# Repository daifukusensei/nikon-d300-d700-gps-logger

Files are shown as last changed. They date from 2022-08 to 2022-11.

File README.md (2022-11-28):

# Project Neptune: Arduino GPS w/ microSD logging and Bluetooth for Nikon D300(S)/D700
This is Project Neptune: an Arduino-based GPS data-logger for Nikon D300, D300S and D700 cameras with USB and Bluetooth connectivity.

<p align="center">
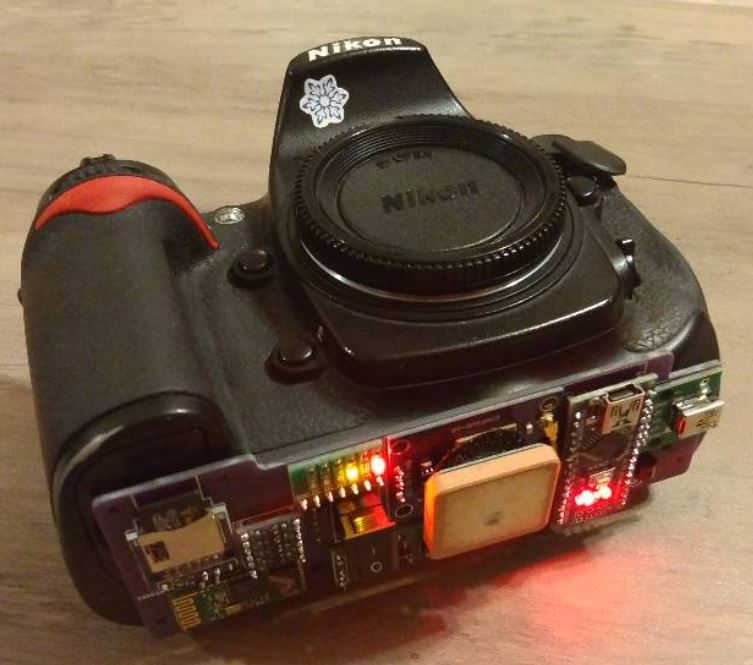
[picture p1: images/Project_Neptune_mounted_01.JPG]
  
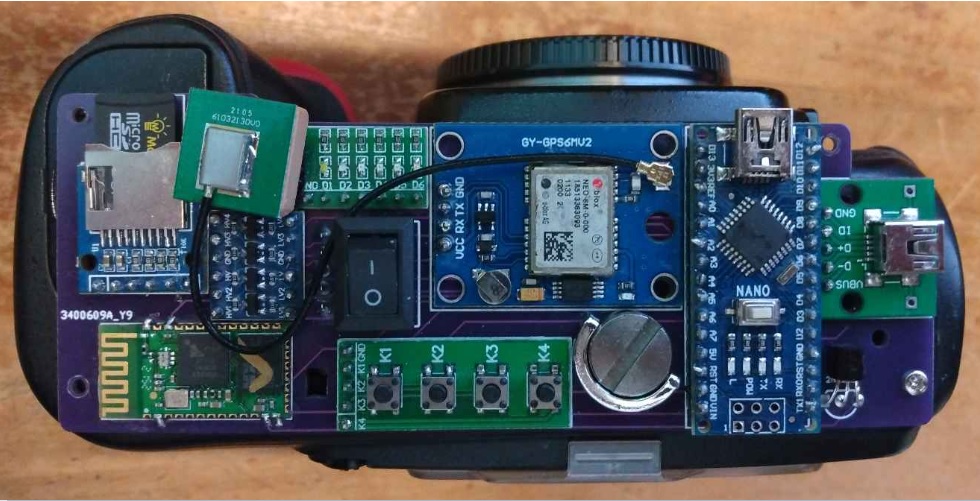
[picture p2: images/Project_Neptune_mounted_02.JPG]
  
</p>

## Why?
I'm an active travel photographer, and use various hardware & software-based GPS solutions to geo-tag my images, all with distinct shortcomings when paired with my ancient (but lovely) Nikon D700. So, I've built a geo-tagging device to meet my own specific needs. (See [Disclaimer](#Disclaimer).)

Leveraging what I've learned from an earlier attempt at a mobile GPS-solution (see [Project Pluto](https://github.com/daifukusensei/arduino-gps-logger)), I've affectionately named this Project Neptune.

## Features
- Mounts to the bottom of a Nikon D300(S)/D700
- Powered directly from camera independent of it being on or off
- Geo-tagging of captured images directly into EXIF metadata via USB-to-10-pin cable
- Logging of co-ordinates to microSD card at 2-second intervals
- Waypoint-marking of points of interest
- Bluetooth pairing with mobile phone or Serial Port Profile (SPP)NMEA 0183-compatible device/DSLR (PIN/passkey 0000)
- LEDs to indicate satellite and Bluetooth fix, and microSD card activity
- Individual features (microSD logging, Bluetooth and LEDs) may be toggled on or off, with settings retained across power-cycles

## Repository Contents
- [Arduino Sketch](./nikon-d300-s-d700-gps-logger.ino) for uploading to an Arduino Nano or compatible clone
- [Gerber file](./pcb/Project-Neptune-Gerber-PCB-v22.08.001.zip) for printing a PCB
- [EasyEDA project](./pcb/Project-Neptune-EasyEDA-project.zip) for modifying the PCB schematic
- [STL file](./stl/Project-Neptune-STL-cover.stl) for 3D-printing a cover

## Parts List
| Quantity | Description | Note |
| --- | --- | --- |
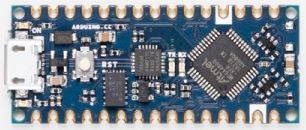
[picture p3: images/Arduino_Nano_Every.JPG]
Image of Arduino Nano Every
| 1 | Arduino Nano/Every or clone w/ soldered straight male headers |  |
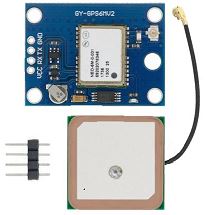
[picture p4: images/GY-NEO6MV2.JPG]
Image of GY-NEO6MV2
| 1 | u-blox NEO-6M GPS module w/ external antenna and built-in EEPROM, and soldered straight male header | Part GY-NEO6MV2:<br/> |
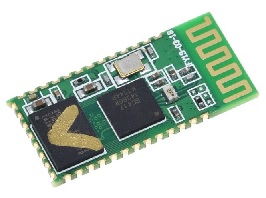
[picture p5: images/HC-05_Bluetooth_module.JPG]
Image of HC-05 Bluetooth module
| 1 | HC-05 Bluetooth module without carrier board |  |
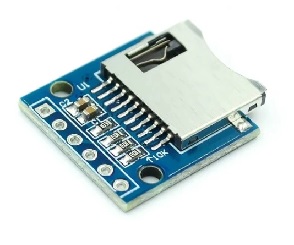
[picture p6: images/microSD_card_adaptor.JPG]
Image of SPI microSD card adaptor
| 1 | SPI microSD card adaptor w/ soldered straight male header | Of the following form-factor:<br/> |
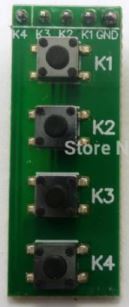
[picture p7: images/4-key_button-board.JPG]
Image of 4-key button-board module
| 1 | 4-key button-board module w/ soldered straight male header | |
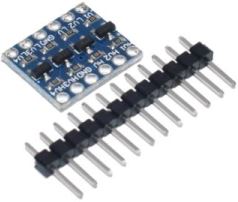
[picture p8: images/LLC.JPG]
Image of LLC
| 1 | 4-channel 3.3V/5V bi-directional logic-level-converter (LLC) w/ soldered straight male headers | Of the following form-factor:<br/> |
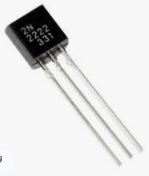
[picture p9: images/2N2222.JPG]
Image of 2N2222
| 1 | 2N2222 NPN transistor | For turning on and off the HC-05 Bluetooth module<br/> |
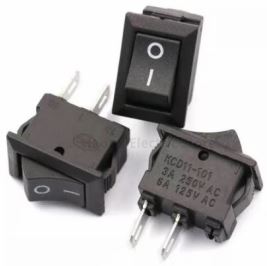
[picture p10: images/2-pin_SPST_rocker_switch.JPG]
Image of 2-pin SPST rocker switch
| 1 | 2-pin SPST rocker switch | 15mm\*10mm, in the following form-factor:<br/> |
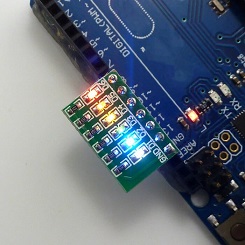
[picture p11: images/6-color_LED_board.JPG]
Image of LED board
| 1 | 3.3V/5V/12V 6-color LED board | Of the following form-factor:<br/> |
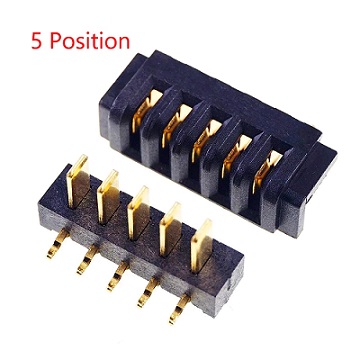
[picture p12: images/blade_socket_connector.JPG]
Image of Blade socket connector
| 1 | 5-position 2.5mm pitch female blade socket connector |  |
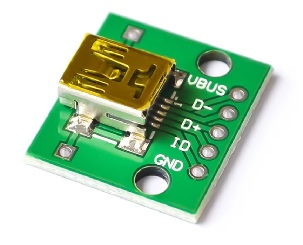
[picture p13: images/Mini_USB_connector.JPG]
Image of Mini-USB connector
| 1 | Female Mini-USB connector on 2.54mm pitch breakout board | Approximately 20mm*18mm, in the following form-factor:<br/>  |
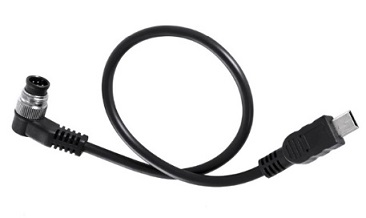
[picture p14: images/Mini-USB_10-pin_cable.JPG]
Image of Mini-USB to 10-pin cable
| 1 | Mini-USB to 10-pin cable | For connecting Project Neptune to the Nikon D300(S)/D700. The cable used for the *Micnova GPS-N1* GPS works fine; otherwise, if making your own, USB pin 3 connects to camera's RX, and USB pin 5 to GND<br/>  |
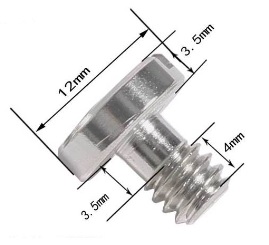
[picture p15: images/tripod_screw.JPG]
Image of tripod screw
| 1 | 1/4-inch tripod screw w/ head diameter no larger than 12mm | For securing Project Neptune to the camera-- the smaller and shorter the better so as to not make contact with PCB components:<br/>  |

## Libraries and Compile Requirements
Project Neptune uses the following libraries:
- [EEPROM](https://www.arduino.cc/en/Reference/EEPROM)
- [NeoGPS](https://github.com/SlashDevin/NeoGPS)
- [SdFat](https://github.com/greiman/SdFat)
- [SoftwareSerial](https://www.arduino.cc/en/Reference/softwareSerial)
- [SPI](https://www.arduino.cc/en/reference/SPI)

I had to do the following to compile against the Arduino Nano *Every*, though these changes may no longer be required and are not needed if an older Arduino Nano is used:
- NeoGPS: remove the `class Print` forward declarations from the following files:
    - DMS.h
    - NeoTime.h
- SdFat: set `SPI_DRIVER_SELECT` to `1` in **SdFatConfig.h** per [greiman/SdFat-beta#42](https://github.com/greiman/SdFat-beta/issues/42)
- Change `#define F(str) (str)` in **Arduino.h** to `#define F(str) (const __FlashStringHelper*)(str)`

## Build Instructions
1. Upload [nikon-d300-s-d700-gps-logger.ino](./nikon-d300-s-d700-gps-logger.ino) to an *Arduino Nano* or *Arduino Nano Every*
2. [Print a PCB](https://jlcpcb.com/) from this repository's Gerber file, with the following settings:
    - 2 layers
    - 1.6mm PCB thickness
3. Due to close proximity of other components on the top-side of the PCB, first solder the *5-position 2.5mm pitch female blade socket connector* to the bottom-side of the board, ensuring connector's pins are facing toward the *centre* of the PCB
4. Solder remaining components to their respective place on the PCB according to their footprint (see [image of PCB's top-side](./pcb/images/Project_Neptune_PCB_populated_top.JPG))
5. Find a place to secure your GPS antenna of choice; I've elected to sandwich mine between the *3.3V/5V/12V 6-color LED board* and *SPI microSD card adaptor* using velcro (see [image of PCB's top-side](./pcb/images/Project_Neptune_PCB_populated_top.JPG))
6. Attach Project Neptune to your Nikon D300(S)/D700 using a *1/4-inch tripod screw*. In order to ensure a secure connection, I've had to experiment with tripod screws of various sizes along with using a rubber washer (see [image of completed Project Neptune](./images/Project_Neptune_mounted_02.JPG)). Many holes are situated along the perimeter of the PCB to allow the use of M2 screws and standoffs should additional support be needed
7. Plug the *Mini-USB to 10-pin cable* into the PCB's USB port (**not** the Arduino's USB port!) and the camera
8. Insert a FAT32-formatted microSD card and power on Project Neptune

## Operations

### Startup Sequence
1. Any user-changed settings are restored from EEPROM
2. If **Waypoint-Marker** button is held, the HC-05 Bluetooth module is re-configured as follows:
	1. Baud rate set to 4800 as required for Nikon D300(S)/D700 connectivity
	2. PIN set to 0000
	3. Device name set to *Nikon-D300(S)-D700-GPS-Logger*
3. Initialize access to microSD card if one's inserted; else disable logging
4. Set baud rate of u-blox NEO-6M GPS module to 4800 as required for Nikon D300(S)/D700 connectivity
5. Set compatibility mode on u-blox NEO-6M GPS module and co-ordinate-system to 4-decimal places as required for Nikon D300(S)/D700 connectivity
6. Up-and-running

### Button Functions
| Button | Long-Press (3-seconds) |
| --- | --- |
| **Logging Button** (**K1** on button-board; **D5** on PCB) | Toggle logging to microSD card on and off |
| **Bluetooth Button** (**K2** on button-board; **D6** on PCB) | Toggle Bluetooth on and off |
| **Waypoint-Marker Button** (**K3** on button-board; **D7** on PCB) | **During normal use:**<br/>- Record current co-ordinates in file on microSD card, regardless of logging state<br/>- Requires a satellite-fix and microSD card *inserted at boot*<br/><br/>**During startup:**<br/>- Re-configure HC-05 Bluetooth module as follows: baud rate set to 4800 as required for Nikon D300(S)/D700 connectivity; PIN set to 0000; device name set to *Nikon-D300(S)-D700-GPS-Logger* |
| **LED Button** (**K4** on button-board; **D8** on PCB) | Toggle LEDs on and off |

### LED Behaviour
- **GPS** (red LED on LED board)
    - Blink: No satellite-fix
    - Solid: Satellite-fix
- **Logging** (yellow LED on LED board)
    - Blink: microSD card activity
    - Solid: microSD card not inserted at boot or error writing to card
- **Bluetooth** (blue LED on LED board)
    - Blink: Searching
    - Solid: Paired
    - Off: Bluetooth is disabled
- Long-pressing a button to toggle individual settings on and off results in the respective LED being lit for 2-seconds to visually indicate a state change

### microSD Card Behaviour
- When logging is on:
  1. File **yymmdd_log_nn.txt** is created in the root of the microSD card with a header row each time logging state is changed to **ON** and a date & time is acquired from the GPS (where **yymmdd** equals current UTC date, and **nn** equals incrementing number beginning with 00)
  2. Given a satellite-fix, the following comma-delimited fields are appended to the file at 2-second intervals
     - Latitude
     - Longitude
     - Speed (km/h)
     - Heading (degrees)
     - Altitude (floating-point meters)
     - Date and Time (UTC)
- Waypoint-markers are appended to file **waypoints.txt** in the same format as above, regardless of logging state

## Disclaimer
**Build and use at your own risk.** I am not an electrical engineer, nor a working C++ developer; this is a passion-project constructed in between numerous daddy duties, household chores, and long working hours. That said, it functions as intended, and has yet to blow up.

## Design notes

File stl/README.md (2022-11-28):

# Project Neptune: STL File
For 3D-printing a cover to protect the board

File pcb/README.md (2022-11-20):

# Project Neptune: EasyEDA Project and Gerber File

<p align="center">
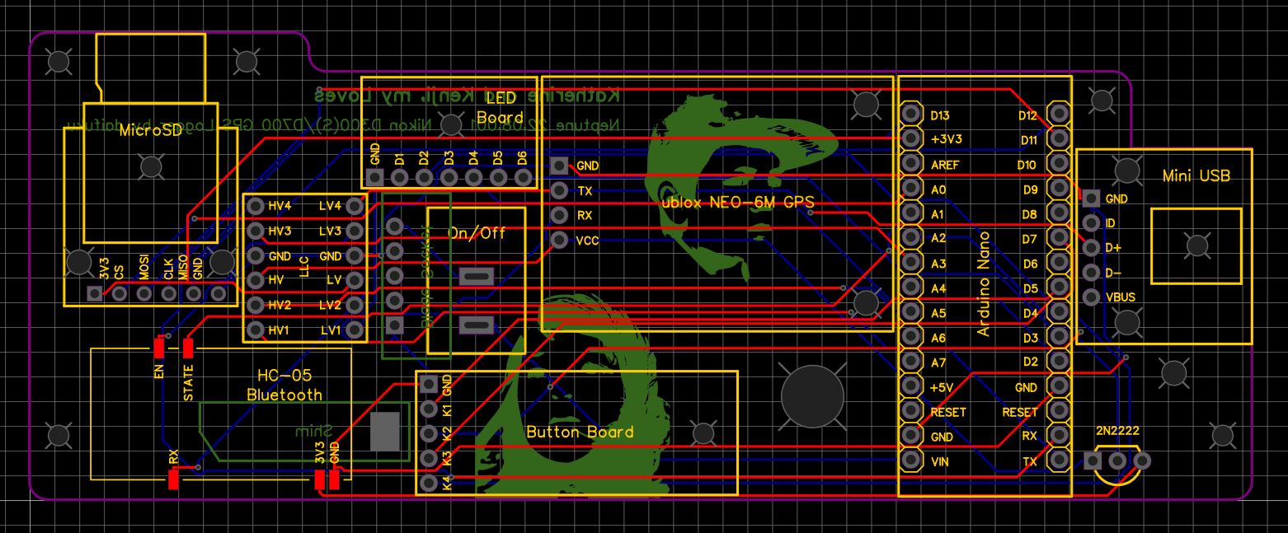
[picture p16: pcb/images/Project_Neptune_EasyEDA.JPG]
  
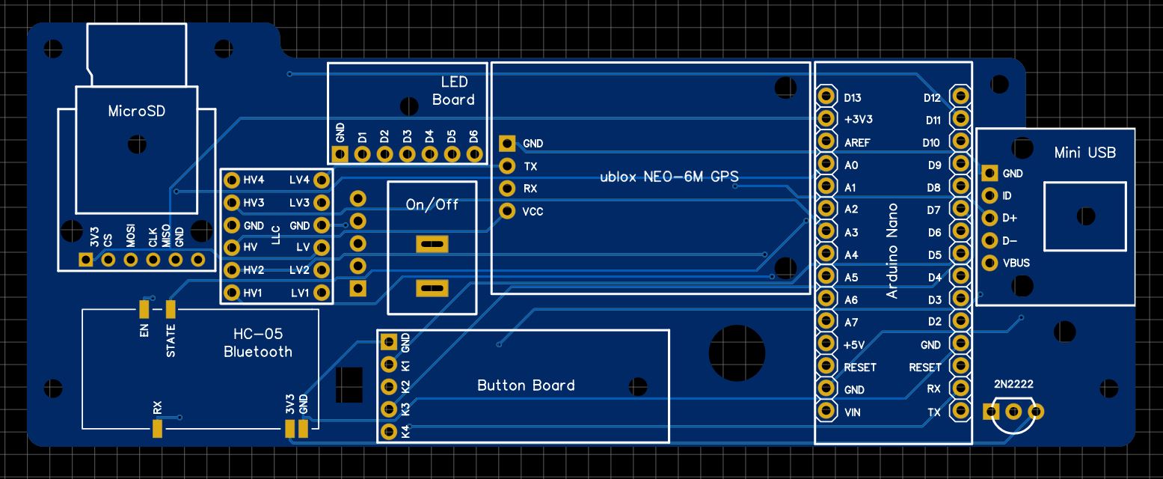
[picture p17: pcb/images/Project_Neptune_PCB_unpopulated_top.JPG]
  
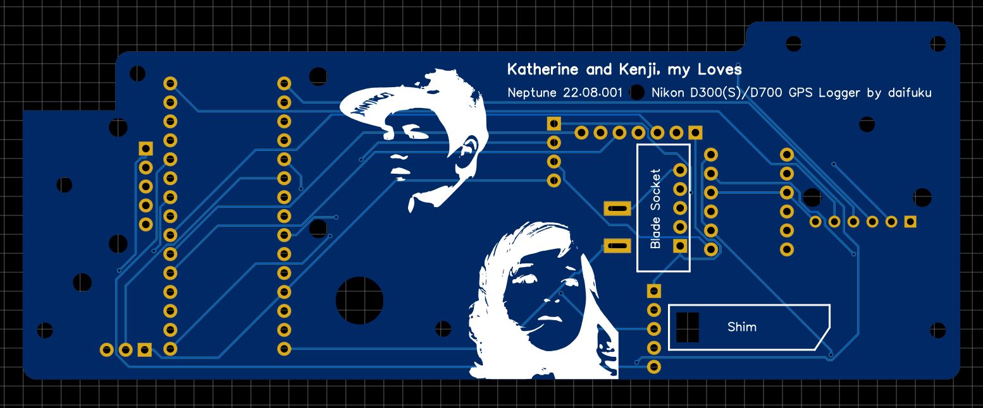
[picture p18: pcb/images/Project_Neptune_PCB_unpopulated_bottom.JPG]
  
</p>

- **Project-Neptune-EasyEDA-project.zip**
    - Zip file containing the schematic and PCB as an editable EasyEDA project
    - Unzip and manually add contents to your EasyEDA project directory

- **Project-Neptune-Gerber-PCB-v22.08.001.zip**
    - A completed PCB, ready for [printing](https://jlcpcb.com/)
    - Print with the following settings:
      - 2 layers
      - 1.6mm PCB thickness

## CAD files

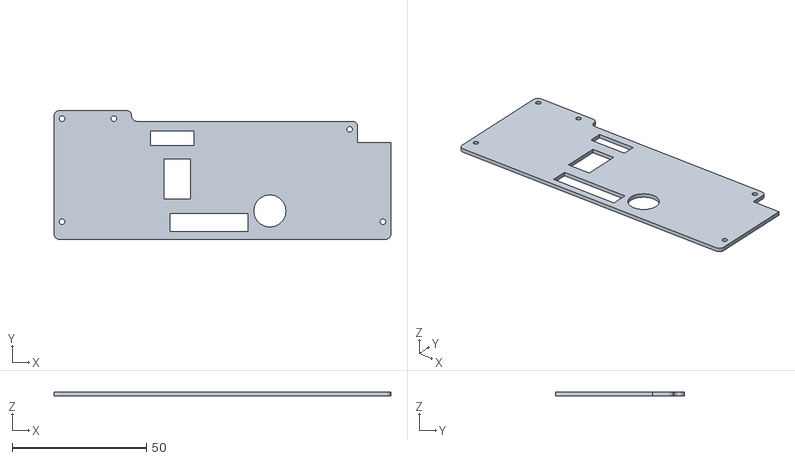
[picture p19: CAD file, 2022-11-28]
stl/Project-Neptune-STL-cover.stl
125.5 x 48.0 x 1.50

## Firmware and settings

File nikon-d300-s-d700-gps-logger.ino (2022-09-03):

// GPS code from https://randomnerdtutorials.com/guide-to-neo-6m-gps-module-with-arduino/
// LED blinking code from https://learn.adafruit.com/multi-tasking-the-arduino-part-1/using-millis-for-timing
// EEPROM code from https://www.arduino.cc/en/Tutorial/EEPROMWrite, https://www.arduino.cc/en/Reference/EEPROMRead
// Software Serial code from https://www.arduino.cc/en/tutorial/SoftwareSerialExample

#include <EEPROM.h>
#include <NMEAGPS.h>
#include <SdFat.h>
#include <SoftwareSerial.h>
#include <SPI.h>

#define GPSPORT Serial // serial port of the connected GPS

#define BTENPIN 17 // the number of the bluetooth HC-05 module's EN pin, used for initiating AT mode to re-configure the device
#define BTRXPIN 19 // the number of the bluetooth HC-05 module's RX pin, used for receiving AT commands issued via serial communication
#define BTVCCPIN 16 // the number of the 2N2222 transistor's base pin, used to power on/off the bluetooth HC-05 module
#define BTSTATEPIN 15 // the number of the bluetooth HC-05 module's state pin, used for controlling the bluetooth state LED
#define BTNLED 8 // the number of the LED state-toggle button's pin
#define BTNBT 6 // the number of the bluetooth state-toggle button's pin
#define BTNLOG 5 // the number of the microSD card logging state-toggle button's pin
#define BTNMARKER 7 // the number of the waypoint-marker button's pin (used for marking a waypoint)
#define LEDBLUETOOTH 4 // the number of the bluetooth LED
#define LEDGPS 3 // the number of the GPS-fix LED
#define LEDLOG 2 // the number of the logging LED (indicates writes to microSD card)

SoftwareSerial BTSERIAL(20, BTRXPIN); // RX, TX on Arduino board

// define button struct
typedef struct Btn {
  Btn(byte pin); // the physical number of the button's pin
  byte pin; // the physical number of the button's pin
  byte currState = 0; // current state of button press (LOW or HIGH)
  byte lastState = 0; // prior state of button press for comparison during program execution
  boolean ignore = false; // used to help manage button presses
  boolean longPress = false; // indicates when a button was long-pressed
  unsigned long millisDown = 0; // milliseconds since a button has first been held
  unsigned long millisUp = 0; // milliseconds since a button has been released
  void checkState(); // method for checking the state of each button
};

// define led class
typedef struct Led {
  Led(byte pin); // the physical number of the LED's pin
  byte pin; // the physical number of the LED's pin
  boolean turnOff = false; // flag to set LED state to LOW (off) on next pass of checkLeds() function
  unsigned long millisLedOnStart = 0; // milliseconds since last time LED was first turned on
  byte millisLedOnMax; // max milliseconds of on-time for LED when blinking
  short int millisLedOffMax; // max milliseconds of off-time for LED when blinking
  void blink(); // method for blinking LED at defined intervals with each pass of checkLeds() function
  boolean longBlink = false; // flag to indicate that LED should remain on for an extended period of time at next blink interval
  void turnOn(); // method for immediately setting LED state to HIGH (on)
};

Btn btnLedState(BTNLED); // create a Btn object for the LED state-toggle button
Btn btnBluetooth(BTNBT); // create a Btn object for the bluetooth state-toggle button
Btn btnLogging(BTNLOG); // create a Btn object for the microSD card logging state-toggle button
Btn btnMarker(BTNMARKER); // create a Btn object for the waypoint-marker button (used for marking a waypoint)
Led ledBluetooth(LEDBLUETOOTH); // create an Led object for the bluetooth LED
Led ledGps(LEDGPS); // create an Led object for the GPS-fix LED
Led ledLog(LEDLOG); // create an Led object for the logging LED (indicates writes to microSD card)

NMEAGPS gps; // GPS object
gps_fix fix; // GPS fix structure
SdFat SD; // microSD card object
File logfile; // file to log to on microSD card

// define constants
const byte sdCSPin = 14; // the number of the microSD card adapter CS pin
const unsigned short int baud = 4800; // target baud rate of the bluetooth and GPS modules
const short int millisBtnLongPressMax = 2000; // max milliseconds before a button long-press is detected
const short int millisLoggingInterval = 2000; // interval between writes to microSD card

// define global variables
boolean sdCardReady = false; // used to indicate if microSD card is ready
boolean sdLogReady = false; // used to indicate if a logfile on microSD has been created and is available for writing
unsigned long millisLoggingStart = 0; // milliseconds since last time access to the microSD card was initiated
char logfileName[] = "yymmdd_log_##.txt"; // dynamic track logging filename on microSD card (based on unique date & number-sequence)

// initial state parameters
boolean setBluetoothOn = false; // bluetooth is either OFF or ON (default OFF)
boolean setLedOn = true; // LEDs are either ON or OFF (default ON)
boolean setLoggingOn = false; // logging is either OFF or ON (default OFF)

void setup() {  
  //setDefaults();  // erase EEPROM and set to defaults
 
  // read EEPROM values into memory
  readEeprom();

  // intialize the LEDs
  ledBluetooth.millisLedOnMax = 100;
  ledBluetooth.millisLedOffMax = 1000;
  ledGps.millisLedOnMax = 100;
  ledGps.millisLedOffMax = 1000;
  ledLog.millisLedOnMax = 100;

  pinMode(BTENPIN, OUTPUT);
  digitalWrite(BTENPIN, LOW); // bluetooth HC-05 module's EN pin is only used when re-configuring the device, and is thus set to LOW
  pinMode(BTVCCPIN, OUTPUT);
  digitalWrite(BTVCCPIN, LOW); // start with bluetooth HC-05 module off unless user settings (read later from EEPROM) indicate otherwise
  pinMode(BTRXPIN, INPUT); // set Arduino's TX pin (bluetooth HC-05 module's RX pin) to input mode so as to not interfere with GPS
                           // NMEA sentences being sent to the HC-05 module's same RX pin and the same 'line' to Arduino's serial RX--
                           // perhaps one day I'll learn enough to figure out the issue and why input mode works

  // should such settings have been lost, reset the bluetooth HC-05 module's baud rate, pin and role to what's required
  // of slave operations by holding the waypoint-marker button when powering on-- may require a few attempts
  if (digitalRead(btnMarker.pin) == LOW) {
    ledBluetooth.turnOn(); // immediately turn on the bluetooth LED to indicate attempted reset of bluetooth HC-05 module
    resetBluetooth(baud);
  }
  
  // initialize the microSD card
  sdInit();

  GPSPORT.begin(9600); // open serial connection with GPS at default baud rate of 9600
  
  setGpsBaudRate(baud); // set the GPS baud rate to 4800 with each startup
  byte compatMode[] = { 0xB5, 0x62, 0x06, 0x17, 0x04, 0x00, 0x00, 0x23, 0x00, 0x03, 0x47, 0x55, 0xE3, 0xC6 };
  sendUBX(compatMode, sizeof(compatMode) / sizeof(byte)); // set the GPS compat flag via a u-blox UBX-CFG-NMEA command to enable
                 // compatibility mode and present co-ordinates in 4 decimal places rather than 5, required for Nikon cameras
}

void loop() {
  checkBtns(); // check state of buttons
  checkLeds(); // take action on LEDs (blink, turn off, etc.)
  checkSerialData(); // check incoming serial data and pass to gps object
  checkBluetooth(); // take actions against bluetooth HC-05 module
  checkLogger(); // take logging actions
}

void checkBtns() {
  btnLedState.checkState();
  btnBluetooth.checkState();
  btnLogging.checkState();
  btnMarker.checkState();

  // toggle LED state
  if (btnLedState.longPress) { // the LED state-toggle button was long-pressed
    setLedOn = ! setLedOn; // toggle LED state and write to EEPROM
    writeEeprom();
  }
  
  // add a waypoint-marker
  if (btnMarker.longPress) { // the waypoint-marker button was long-pressed
    if (sdCardReady) { // attempt to mark a waypoint only if microSD card is accessible
      if (fix.valid.location) {
        ledLog.longBlink = true; // indicate that logging LED should remain on for a brief period of time to visually indicate a
                                 // waypoint was written to file
        sdWriteMarker(); // write a waypoint to file      
      }
    }
  }

  // toggle bluetooth state
  if (btnBluetooth.longPress) { // the bluetooth state-toggle button was long-pressed
    ledBluetooth.longBlink = true; // indicate that bluetooth LED should remain on for a brief period of time to visually indicate
                                   // change of state
    setBluetoothOn = ! setBluetoothOn; // toggle bluetooth state and write to EEPROM
    writeEeprom();
  }

  // toggle logging state
  if (btnLogging.longPress) { // the microSD card logging state-toggle button was long-pressed
    if (sdCardReady) { // attempt to change logging state only if microSD card is accessible
      ledLog.longBlink = true; // indicate that logging LED should remain on for a brief period of time to visually indicate change of
                               // state
      setLoggingOn = ! setLoggingOn; // toggle logging state and write to EEPROM
      writeEeprom();
    }
  }
}

void Btn::checkState() {
  // reset button state so as to not continually change settings with each loop if button is held too long
  longPress = false;

  currState = digitalRead(pin); // get current state of button to determine if it's been pressed
  if (currState == LOW) { // button is currently DOWN (pressed/held); reset millisDown timer
    millisDown = millis();
    if (((millisDown - millisUp) >= millisBtnLongPressMax) && (! ignore)) { // take action on long-presses
      longPress = true; // indicate that the button was long-pressed
      ignore = true; // indicate that the button is still held to avoid acting on another long-press with each loop
    }
  } else {
    millisUp = millis();
    ignore = false;
  }
    
  lastState = currState; // save state of button press for comparison with each loop
}

void checkSerialData() {
  // wait for all serial data to be consumed from buffer before passing it to the gps object
  while (gps.available(GPSPORT)) {
    fix = gps.read();
  }
}

void checkBluetooth() {
  digitalWrite(BTVCCPIN, setBluetoothOn ? HIGH : LOW); // enable or disable HC-05 module, based on user settings
}

void checkLogger() {
  if (setLoggingOn) {
    if (sdCardReady) {
      if (! sdLogReady) {
        if (fix.valid.date) {
          // create a new date & number-sequenced logfile on microSD card each time the logging state is enabled/re-enabled
          sdCreateLog();
        }
      } else if (millis() - millisLoggingStart >= millisLoggingInterval) {
        // log to microSD card at a specified interval if it's been successfully initialized and a logfile is ready for writing
        sdWriteFile(logfile, logfileName);
      }
    } else {
      setLoggingOn = false; // disable logging as microSD card is not available
    }
  } else {
    sdLogReady = false; // logging state is disabled, so indicate that no logfile is available for writing
  }
}

void checkLeds() { 
  if (setLedOn) { // LEDs are enabled
    // GPS-fix LED
    // blink continuously until a GPS-fix is detected, then remain lit
    if (fix.valid.location) {
      digitalWrite(ledGps.pin, HIGH);
    } else {
      ledGps.blink();
    }
  
    // Bluetooth state LED
    // blink if bluetooth is on until pairing is established, then remain lit
    if ((setBluetoothOn) || (ledBluetooth.longBlink)) { // bluetooth is enabled or longBlink flag was set on bluetooth LED,
                                                        // indicating recent change to state (enabled/disabled)
      if (digitalRead(BTSTATEPIN) == HIGH) { // HC-05 module's state pin indicates a device is paired, so turn on bluetooth LED
        digitalWrite(ledBluetooth.pin, HIGH);
      } else {
        ledBluetooth.blink(); // bluetooth is enabled but no device is yet paired, so blink
      }  
    } else {
      digitalWrite(ledBluetooth.pin, LOW); // bluetooth is disabled, so turn off LED
    }

    // Logging state LED
    if (! sdCardReady) {
      digitalWrite(ledLog.pin, HIGH); // stay on if microSD card is not yet ready, to indicate there's a problem...
    } else if (ledLog.longBlink) {
      ledLog.blink(); // ...else, remain on for a brief period of time if either the waypoint-marker or logging buttons were
                      // long-pressed to add a marker or change logging state respectively, or turn off LED (below) if we've manually
                      // flagged to do so via turnOff boolean
    } else if ((digitalRead(ledLog.pin) == HIGH) && (ledLog.turnOff) && (millis() - ledLog.millisLedOnStart >= ledLog.millisLedOnMax)) {
      ledLog.millisLedOnStart = millis(); // remember the time
      digitalWrite(ledLog.pin, LOW); // update the actual LED
      ledLog.turnOff = false;
    }
  } else {
    ledBluetooth.longBlink = false; // longBlinks are only reset to false on next call of an LED's blink routine, which doesn't occur
                                    // with LEDs off- so set longBlinks to false here should long-presses have occured while LEDs, to
                                    // avoid having them longBlink when LEDs are next turned on
    ledGps.longBlink = false;
    ledLog.longBlink = false;
    digitalWrite(ledBluetooth.pin, LOW);
    digitalWrite(ledGps.pin, LOW);
    digitalWrite(ledLog.pin, LOW);
  }
}

void Led::blink() {
  if ((digitalRead(pin) == HIGH) && (millis() - millisLedOnStart >= (longBlink ? millisLedOnMax * 20 : millisLedOnMax))) {
    millisLedOnStart = millis(); // remember the time
    digitalWrite(pin, LOW); // update the actual LED
    longBlink = false; // exceeded time LED is to remain on, so set longBlink flag to false regardless of it's prior state
  } else if (digitalRead(pin) == LOW) {
    if ((millis() - millisLedOnStart >= millisLedOffMax) || (longBlink)) { // set LED to high if we've exceeded time LED
                                                                           // is to remain off, OR longBlink was flagged
      millisLedOnStart = millis(); // remember the time
      digitalWrite(pin, HIGH); // update the actual LED
    }
  }
}

void Led::turnOn() {
  // function to immediately turn on LED
  if ((setLedOn) && ! (longBlink)) { // turn on LED only if user has enabled them AND a long-press has not already occurred
                                     // to result in a longBlink, in order to avoid timing issues when blinking it on and off
                                     // from the checkLeds routine- otherwise the logging LED will remain lit longer than
                                     // expected during logging state change 
    digitalWrite(pin, HIGH); // update the actual LED
    millisLedOnStart = millis(); // remember the time
  }
}

void readEeprom() {
  // first check if the used EEPROM address space includes any bytes with values of 255, which is outside the
  // range of our stored values and is indicative of a default Arduino EEPROM state
  for (char eepromAddr = 0; eepromAddr <= 2; eepromAddr++) {
    if (EEPROM.read(eepromAddr) == 255) { // not within range, so set parameters to usable defaults and write to EEPROM
      setDefaults();
      break;
    }
  }

  setBluetoothOn = EEPROM.read(0); // read index of bluetooth state setting from EEPROM
  setLedOn = EEPROM.read(1); // read index of LED state setting from EEPROM
  setLoggingOn = EEPROM.read(2); // read index of logging state setting from EEPROM
}

void writeEeprom() {
  EEPROM.update(0, setBluetoothOn); // write index of bluetooth state setting to EEPROM only if changed
  EEPROM.update(1, setLedOn); // write index of LED state setting to EEPROM only if changed
  EEPROM.update(2, setLoggingOn); // write index of logging state setting to EEPROM only if changed
}

void setDefaults() {
  setBluetoothOn = false;
  setLedOn = true;
  setLoggingOn = false;

  writeEeprom();
}

void resetBluetooth(unsigned short int baud) {
  digitalWrite(BTVCCPIN, LOW); // turn off bluetooth HC-05 module if it's not already off
  delay(100);
  digitalWrite(BTENPIN, HIGH); // set bluetooth HC-05 module to AT mode by first bringing up EN pin before applying power (VCC)
  delay(100);
  digitalWrite(BTVCCPIN, HIGH);
  pinMode(BTRXPIN, OUTPUT); // set Arduino's TX pin (bluetooth HC-05 module's RX pin) to output mode to enable serial communication
  delay(250);

  BTSERIAL.begin(38400); // open serial connection with bluetooth HC-05 module
  delay(250);
  
  BTSERIAL.write("AT\r\n"); // oddly, after toggling BTRXPIN from input to output, an initial AT command needs to first be sent to 'wake
                            // up' the bluetooth HC-05 module, after which subsequent commands will be accepted
  delay(1000); // shorter delays resulted in subsequent AT commands not being acknowledged
  switch(baud) { // send to the bluetooth HC-05 module the required AT command for changing its baud rate
    case 4800:
      BTSERIAL.write("AT+UART=4800,0,0\r\n");
      break;

    case 9600:
      BTSERIAL.write("AT+UART=9600,0,0\r\n");
      break;

    default:
      break;
  }
  delay(1000);

  BTSERIAL.write("AT+PSWD=\"0000\"\r\n"); // reset the bluetooth HC-05 module's pin
  delay(1000);

  BTSERIAL.write("AT+NAME=Nikon-D300(S)-D700-GPS-Logger\r\n"); //set name
  delay(1000);

  BTSERIAL.write("AT+ROLE=0\r\n"); // reset the bluetooth HC-05 module's role to slave
  delay(1000);

  BTSERIAL.end(); // close serial connection with bluetooth HC-05 module
  digitalWrite(BTENPIN, LOW);
  digitalWrite(BTVCCPIN, LOW); // cut power to bluetooth HC-05 module
  delay(100);
  pinMode(BTRXPIN, INPUT); // set Arduino's TX pin (bluetooth HC-05 module's RX pin) to input mode so as to not interfere with GPS
                           // NMEA sentences being sent to the HC-05 module's same RX pin and the same 'line' to Arduino's serial RX--
                           // perhaps such interference is due to additional voltage leaking over from Arduino when in output mode, thus
                           // malforming the GPS feed? Perhaps one day I'll learn enough to figure out the issue and why input mode works
  digitalWrite(BTVCCPIN, setBluetoothOn ? HIGH : LOW); // power up bluetooth HC-05 module if needed, based on user settings
  delay(100);
}

void setGpsBaudRate(unsigned short int baud) {
  for (int i = 0; i < 2; i++) {
    delay(100);

    switch(baud) { // send to the u-blox NEO-6M GPS the required NMEA sentence for changing its baud rate
      case 4800:
        GPSPORT.write("$PUBX,41,1,0007,0003,4800,0*13\r\n");
        break;

      case 9600:
        GPSPORT.write("$PUBX,41,1,0007,0003,9600,0*10\r\n");
        break;

      default:
        break;
    }

    delay(100);
    GPSPORT.end();
    delay(100);
    GPSPORT.begin(9600); // we attempt to set the baud rate twice- initially with the connected serial port already open should the GPS
                         // currently be active and accepting of commands, and again with the connected serial port re-opened at the GPS'
                         // default baud rate of 9600 should it have forgotten any previous configuration changes
  }

  delay(100);
  GPSPORT.end();
  delay(100);
  GPSPORT.begin(baud); // re-open the serial port at our desired baud rate
}

void sendUBX(byte *command, byte len) {
  // compat mode command courtesy of: https://www.navilock.com/service/fragen/gruppe_59_uCenter/beitrag/101_ublox-Center-Compatibility-Mode-since-ublox-6.html
  // backup mode command courtesy of: https://forum.arduino.cc/index.php?topic=497410.0
  //                                  https://ukhas.org.uk/guides:ublox_psm
  // checksum calculation courtesy of: https://gist.github.com/tomazas/3ab51f91cdc418f5704d

  for (byte i = 0; i < len; i++) {
    GPSPORT.write(command[i]);
  }
}

void sdInit() {
  // see if the microSD card is present and can be initialized
  if (SD.begin(sdCSPin)) {
    sdCardReady = true; // indicate we're ready to begin logging
  }
}

void sdCreateLog() {
  // pick a new date & number-sequenced filename with each power cycle
  sprintf(logfileName, "%02d%02d%02d", fix.dateTime.year, fix.dateTime.month, fix.dateTime.date); // get current date from GPS
  strcat(logfileName, "_log_##.txt"); // append _##.txt to filename*/

  for (uint8_t i = 0; i < 100; i++) {
    logfileName[11] = '0' + i/10;
    logfileName[12] = '0' + i%10;
    if (! SD.exists(logfileName)) {
      // use this one!
      break;
    }
  }

  logfile = SD.open(logfileName, FILE_WRITE);
  if (logfile) {
    ledLog.turnOn(); // turn on logging LED immediately
    //logfile.println( F("Latitude,Longitude,Speed (km/h),Heading (degrees),Altitude (floating-point meters),Date and Time (UTC)") );
    logfile.println("Latitude,Longitude,Speed (km/h),Heading (degrees),Altitude (floating-point meters),Date and Time (UTC)");
    logfile.flush(); // close file after each write as only a single file can be open at a time
    ledLog.turnOff = true; // indicate that logging LED should be turned off at next pass of checkLeds() function
    
    sdLogReady = true; // indicate that a new logfile is available for writing
  } else {
    sdCardReady = false; // there was a problem creating a new logfile, so set microSD card ready state to false to visually report a problem
    setLoggingOn = false; // disable logging as microSD card is not available
  }
}
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

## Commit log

2022-08-07 Removed resetting of HC-05 baud rate
    [nikon-d300-s-d700-gps-logger.ino]
2022-08-27 Initial EasyEDA schematic and PCB design
2022-09-02 Reset HC-05 to required settings
    -added ability to reset the Bluetooth HC-05 module to required settings should they have been lost
    [nikon-d300-s-d700-gps-logger.ino]
2022-09-03 Set HC-05 name upon reset
    -set Bluetooth HC-05 module's visible name to "Nikon-D300(S)-D700-GPS-Logger" upon resetting it to required settings
    [nikon-d300-s-d700-gps-logger.ino]
2022-09-03 Updated PCB
2022-09-17 Cleaned up repository
    [Fritzing-circuit-diagram.fzz, Project-Pluto-enclosure-battery-cover.stl, Project-Pluto-enclosure-bottom.stl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]
2022-11-18 Updated READMEs
    - updated main README
    - added PCB/README
2022-11-20 Updated README
    - updated build instructions
    - added populated PCB image
2022-11-20 Updated README
    - completed build instructions
    - added additional images of completed PCB
    - cleaned up images
2022-11-28 Added STL file
    - for 3D-printing a cover to protect the board
    [Project-Neptune-STL-cover.stl]
